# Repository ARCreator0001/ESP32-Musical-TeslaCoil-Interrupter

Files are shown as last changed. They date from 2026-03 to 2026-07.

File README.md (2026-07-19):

# ESP32 Musical Tesla Coil interrupter - a truly versatile interrupter








Demo video of it working!!(YouTube)
[Demo!!](https://youtu.be/YgG9X8sHGf4)

Link to onshape: [Onshape](https://cad.onshape.com/documents/e0858d62bc807065493100b9/w/9e573f9273f6c5cefa0e0909/e/5fb6c5c268f4d3541bf88c26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)

## Why? 

I always wanted a good, cheap and reliable Tesla Coil Interrupter but as of now, there is not a good, easily accessible proper product like project or prototype I could get. And I needed a good, feature rich, safe interrupter too for my Tesla Coil journey since all my prototype perfboard designs failed of the harsh environments. I wanted something close to the OneTesla SD interrupter but a modern touch, more modern features that make sense and a lot of new features that is essential nowadays. 
 
That is why I set out to build a good, ESP32S3 based Tesla Coil interrupter that is reliable as a product and robust for the environments of a Tesla Coil.

## About the project in a nutshell

It is a portable fiber optic(POF) output interrupter designed to interrupt DRSSTCs and SSTCs safely with limits, and even audio modulate the interruption for musical tesla coil arcs! 
It has an easy to use UI, simple settings on the frontend, and importantly, it has so much limits and safeties specifically tuned for DRSSTC to ensure the coil and driver is not stressed very much. 

It is powered by a 9V battery inside the battery compartment by default, but USB C power input(compatible with modern chargers) can also be used by changing a mode select jumper. 

## Hardware it uses and more features

- Compact 16x2 LCD for displaying information. 
- Micro SDcard slot for music. It supports playing  .mid file and even OneTesla's propietary binary music data file (.omd) used kn their interrupters as a fallback. 
- 4 Voices support for midi files(2 voice for  .omd) means more complex music can be played! 
- Optical fiber output (POF 1mm) for output to coil driver, ensuring isolation from EM radiation and noise. 
- Live mode MIDI over serial through DIN 5 jack and also USB MIDI support is present (usb midi needs firmware addition yet) 
- Tactile Buttons and Rotary encoder(setting volume and also for selection) for the UI and adjustments in operation. There is also a latching power switch. 
- Fixed-frequency mode with adjustable freq and volume

## How to use. 

- Press the latching switch. The device will turn on and display by default Fixed Mode. 
- Left&Right buttons can be used to scroll through menus. Select is done by pressing on the rotary encodee knob till thr encoder knob clicks. 
- The middle button(used to be select)will become the new exit button to exit out of modes(yet to be totally verified in firmware)
- To play fixed freq pulses select fixed mode. Rotating rotary knob when the Freq is selected will change the frequency, to select volume, left or right button is used till bottom row of LCD is highlighted,then volume(duty cycle) can be adjusted by rotary knob. Middle button will be used to exit the mode.Note optical output starts once in fixed mode(default 20Hz with minimum volume) and will stop once exited. 

- For live modes(Live&MIDI BLE), an input such as from a keyboard or any device can be given to the interrupter in live. The device will act as Midi receiver. 

# Firmware details

## Build & Upload (Arduino IDE)
 Please install the ESP32 board core before proceeding
 The interrupter after building needs to be programmed with firmware. The latest firmware files can be accessed in releases. 

1. Board: Select **ESP32S3 Devkit** (or ESP32S3 Dev Module)

2. Libraries: Unlike previous firmware versions, Now the libraries are included within the firmware locally

3. Select correct COM port, Upload.

## Controls

- **Main menu**: LEFT/RIGHT to navigate; SELECT(rotary's switch) to enter, soon mid button for exiting. 
- **Fixed mode**: short SELECT toggles freq/volume adjust; Press middle button to exit

- **Live mode&MIDI BLE**: SELECT activates and exits live mode. Status is shown in LCD. 

- **SD browser**:LEFT/RIGHT to navigate through files & directories; SELECT opens folder or plays file; press middle button to go one up if inside directories or exit the mode if in root directory. 

- **Playback**: SELECT starts & stops; Rotary knob rotation adjusts volume bar(the coil duty)

## File format

- It accepts .mid MIDI files. More than 4 channels won't play correctly, always keep melody in first two as they are preferred internally. 
-It also uses .omd file but it is a limited fallback only, it is a cut down midi file format OneTesla used so your music may not play properly. Soon  .omd will be disabled by default. 

# CAD images and images of PCB & schematic





PCB images








All mech parts in parts studio



Exploded views





Here is schematic
SCH_ESP32 SD Interrupter_1-Sheet_1_2026-03-31

# Bill of materials

| Part name | Qty required(not ordered due to MOQs) | Source | Price | Actual Price with taxes & shipping | Links |
| --- | --- | --- | --- | --- | --- |
| PCB board fabrication | 1 used 5 MOQ |Lion Circuits or ~~Robu.in~~ | ~~robu(₹3556/$37.7)~~, Lion ₹2983 $31.74 | ~~robu(same)~~,Lion ₹2983 $31.74 |Cannot link to quote|
| 2.54MM male Pin headers | 5 pins(2+3) | Local shop | Already own | Already own | |
|Power Switch Latching|1|LCSC|$0.84|$0.84|[link](https://www.lcsc.com/product-detail/C22386787.html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)|
|USB C Port Connector|1|LCSC|$1.06|$1.06|[link](https://www.lcsc.com/product-detail/C20624793.html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)|
|Tactile Button|3|LCSC|$0.06|$0.06|[link](https://www.lcsc.com/product-detail/C7528723.html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)|
|OptoTransmitter HFBR-1521Z|1|LCSC|$7.65|$7.65|[link](https://www.lcsc.com/product-detail/C188712.html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)|
|AMS1117-3.3 regulator|1|LCSC|$1.13|$1.13|[link](https://www.lcsc.com/product-detail/C6186.html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)|
|AMS1117-5.0 regulator|1|LCSC|$1.19|$1.19|[link](https://www.lcsc.com/product-detail/C6187.html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)|
|ESP32S3 Wroom 1 N8|1|LCSC|$5.42|$5.42|[link](https://www.lcsc.com/product-detail/C2913198.html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)|
|10uF 25V Aluminum Electrolytic Cap|1|LCSC|$0.49|$0.49|[link](https://www.lcsc.com/product-detail/C43846.html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)|
|100nF 25V 0805 Ceramic cap|8|LCSC|$0.18|$0.18|[link](https://www.lcsc.com/product-detail/C53084462.html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)|
|470Ω 150V Thin Film Resistor|1|LCSC|$0.70|$0.70|[link](https://www.lcsc.com/product-detail/C479100.html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)|
|220Ω 0805 Res|1|LCSC|$1.70|$1.70|[link](https://www.lcsc.com/product-detail/C186237.html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)|
|180Ω 0805 Res|1|LCSC|$0.49|$0.49|[link](https://www.lcsc.com/product-detail/C313842.html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)|
|33ohm 0805 Res|1|LCSC|$0.41|$0.41|[link](https://www.lcsc.com/product-detail/C557530.html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)|
|Rotary encoder EC11E18244A5|1|LCSC|$2.05|$2.05|[link](https://www.lcsc.com/product-detail/C255515.html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)|
|Micro SD TF card port|1|LCSC|$0.73|$0.73|[link](https://www.lcsc.com/product-detail/C111196.html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)|
|10K Resistor array 1206|1|robu.in|₹ 2.28 $0.0243|₹ 2.28 $0.0243|[link](https://robu.in/product/cay16-1002f4lf-bourns-4-%c2%b11-10k%cf%89-62-5mw-%c2%b1200ppm-%e2%84%83-1206-resistor-networks-arrays-rohs/)|
|0805 LED Green|1|robu.in|₹ 2.62 $0.0279|₹ 2.62 $0.0279|[link](https://robu.in/product/0805-surface-mount-led-green-50-pcs/)|
|0805 LED Red|2|robu.in|₹2.36 $0.0252|₹2.36 $0.0252|[link](https://robu.in/product/0805-surface-mount-led-red-50-pcs/)|
|DSS34 diode|2|robu.in|₹ 9.58 $0.1021|₹ 9.58 $0.1021|[link](https://robu.in/product/dss34-slkor-sod-123fl-schottky-diodes-rohs/)|
|1N4148W 1206 Diode|2|robu.in|₹ 1.70 $0.0181| ₹ 1.70 $0.181|[link](https://robu.in/product/1n4148w-sod-123-1206-diodereel-of-3000/)|
|SS8050S-FOSAN-SOT-23 Bipolar (BJT)|1|robu.in|₹1.82 $0.0194| ₹1.82 $0.0194|[link](https://robu.in/product/ss8050s-fosan-sot-23-bipolar-bjt-rohs/)|
|510kΩ 0805 res|1|robu.in|₹0.21 $0.0022||[link](https://robu.in/product/0805w8j0514t5e-uniohm-royal-ohm-125mw-thick-film-resistors-150v-%c2%b1100ppm-%e2%84%83-%c2%b15-510k%cf%89-0805-chip-resistor-surface-mount-ro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)|
|5.1kΩ 0805 res|2|robu.in|₹ 1.96 $0.0209|₹ 1.96 $0.0209|[link](https://robu.in/product/ac0805fr-075k1l-yageo-res-thick-film-0805-5-1k-ohm-1-0-125w1-8w-%c2%b1100ppm-c-pad-smd-t-r-automotive-aec-q200/)|
|2.2Kohm 0805 res|1|robu.in|₹ 0.42 $0.0045|₹ 0.42 $0.0045|[link](https://robu.in/product/ac0805jr-072k2l-yageo-res-thick-film-0805-2-2k-ohm-5-0-125w1-8w-%c2%b1100ppm-c-pad-smd-t-r-automotive-aec-q200/)|
|47Ω 0805 res|1|robu.in|₹ 0.20 $0.0021|₹ 0.20 $0.0021|[link](https://robu.in/product/0805w8f470jt5e-uniohm-royal-ohm-125mw-thick-film-resistors-150v-%c2%b11-%c2%b1200ppm-%e2%84%83-47%cf%89-0805-chip-resistor-surface-mount-rohs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)|
|TS-1088-AR02016 Switch|2|robu.in|₹8.43 $0.0899|₹8.43 $0.0899|[link](https://robu.in/product/1-month-warranty-470/)|
|TLJR106M010S2000-KYOCERA AVX-10uF 10V cap|1|robu.in|₹26 $0.2772|₹26 $0.2772|[link](https://robu.in/product/tljr106m010s2000-kyocera-avx-10uf-10v-2%cf%89-%c2%b120-0805-tantalum-capacitors-rohs/)|
|16V 10uF X5R 0805|2|robu.in|₹1.96 $0.0209|₹1.96 $0.0209|[link](https://robu.in/product/cl21a106kofnnne-samsang-16v-10uf-x5r-%c2%b110-0805-multilayer-ceramic-capacitors-mlcc-smd-smt-rohs/)|
|1.3Kohm 0805 res|1|robu.in|₹ 1.96 $0.021|₹ 1.96 $0.021|[link](https://robu.in/product/rt0805fre071k3l-yageo-125mw-thin-film-resistor-%c2%b150ppm-%e2%84%83-%c2%b11-1-3k%cf%89-0805-chip-resistor-surface-mount-rohs/)|
|M2 X 12mm Female to Female Brass with Nickel plating Hex Threaded Standoff Spacer|4|onlyscrews.in|₹24.8 $0.2644|₹24.8 $0.2644|[link](https://onlyscrews.in/products/m2-x-12mm-female-to-female-brass-with-nickel-plating-hex-threaded-standoff-spacer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)|
|M2 X 10mm Hex (Allen) Socket Head High Tensile(12.9) Black oxide screw (Dia. 2mm, Length 10mm)|8|onlyscrews.in|₹28.8 $0.307|₹28.8 $0.307|[link](https://onlyscrews.in/products/m2-x-10mm-hex-allen-socket-head-high-tensile12-9-black-oxide-screw-dia-2mm-length-10mm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)|
|M2 Plain Washer SS304 (ID. 2.1mm OD:4.5mm T:0.5mm)|4|onlyscrews.in|₹2.4 $0.0256|₹2.4 $0.0256|[link](https://onlyscrews.in/products/m2-x-6mm-hex-allen-socket-head-high-tensile12-9-black-oxide-screw-dia-2mm-length-6mm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)|
|M2 Hex Nut Mild Steel with White Zinc Plating (Dia. 2mm)|4|onlyscrews.in|₹4 $0.0426|₹0.0426|[link](https://onlyscrews.in/products/m2-hex-nut-mild-steel-dia-2mm?variant=50252401246521)|
|M2 X 4mm Brass Threaded Inserts (Dia. 2mm, Length 4mm)|8|onlyscrews.in|₹21.6 $0.23|₹21.6 $0.23|[link](https://onlyscrews.in/products/m2-x-4mm-brass-threaded-inserts?variant=49423172829497)|
|16*2 I2C LCD|1|Local shop|Alr own|Alr own| |
|9V PP3 Battery|1|Local shop|Alr own|Alr own| |
|9V PP3 Battery connector clip|1|Local shop|Will purchase myself|Will purchase myself| |
|Sum||||$58.8217 excluding shipping cost of LCSC of $29.25 and $0.5224 of Robu,LionCircuits is free shipping,OnlyScrews has shipping cost of $0.6397| |
|Grand Total|||||$89.2338| |

Link to onshape doc: [Onshape](https://cad.onshape.com/documents/e0858d62bc807065493100b9/w/9e573f9273f6c5cefa0e0909/e/5fb6c5c268f4d3541bf88c26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)

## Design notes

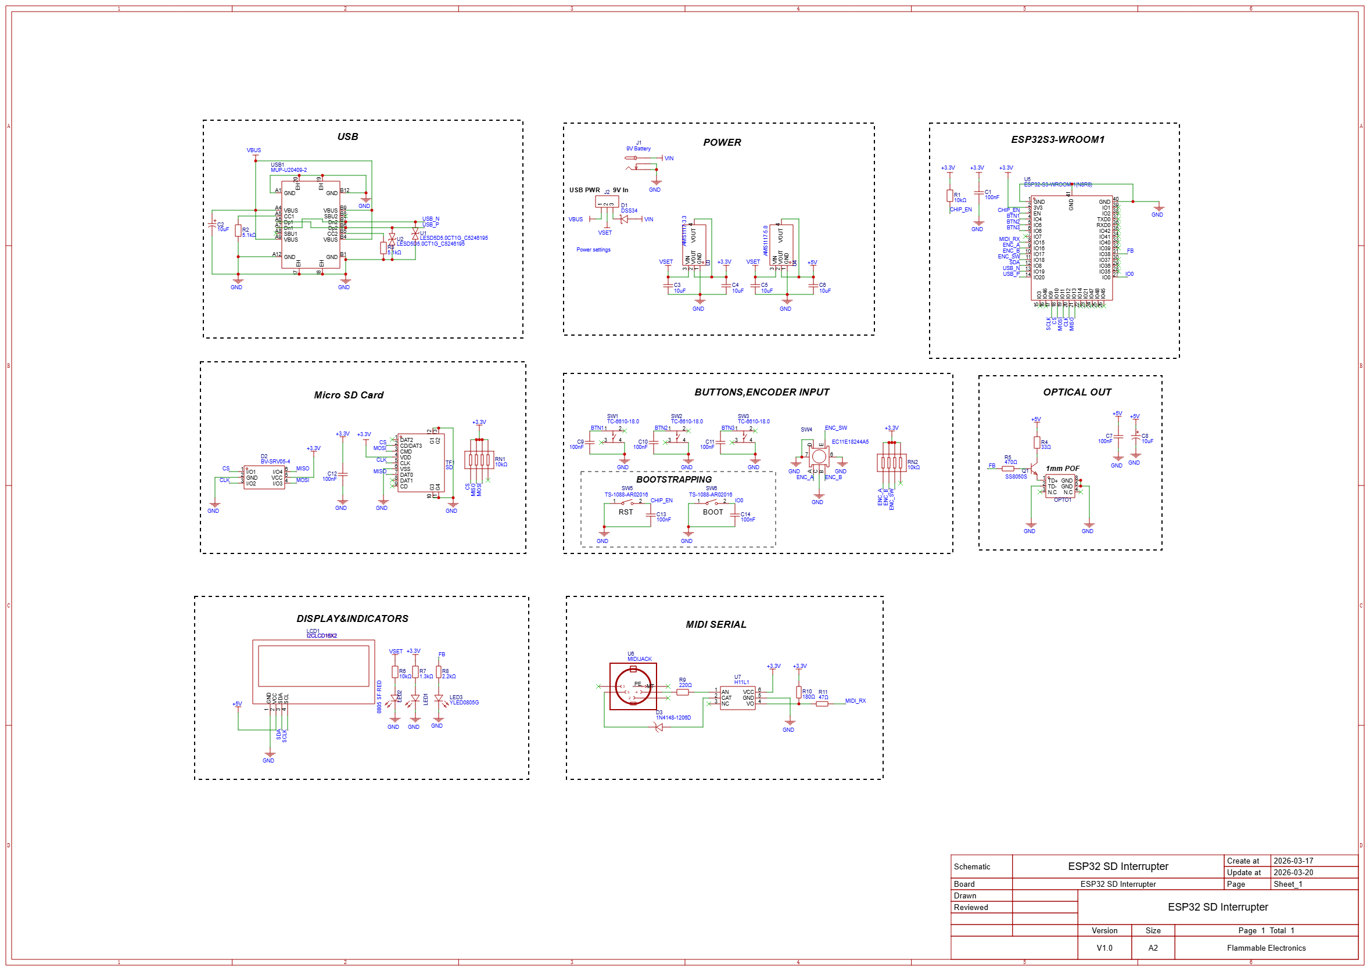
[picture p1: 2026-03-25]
SCH_ESP32 SD Interrupter_1-Sheet_1_2026-03-23.png

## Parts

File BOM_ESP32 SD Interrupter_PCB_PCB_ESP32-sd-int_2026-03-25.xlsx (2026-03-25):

No. | Quantity | Comment | Designator | Footprint | Value | Manufacturer Part | Manufacturer | Supplier Part | Supplier | Name
1 | 6 | 100nF | C1,C9,C10,C11,C13,C14 | C0805 |  | C2012X7R1H104KT0J0N | TDK | C76644 | LCSC | 100nF
2 | 1 | 10uF | C2 | CAP-SMD_L3.2-W2.8-FD |  | T494B106K010AT | KEMET(基美) | C2798063 | LCSC | 10uF
3 | 4 | 10uF | C3,C4,C5,C6 | C0805 |  | CL21A106KOQNNNE | SAMSUNG(三星) | C1713 | LCSC | 10uF
4 | 2 | 100nF | C7,C12 | C0805 |  | CC0805X7R25V104KN | TORCH(火炬) | C53084462 | LCSC | 100nF
5 | 1 | 10uF | C8 | CAP-TH_BD4.0-P1.50-D0.8-FD |  | KF106M025C05RR0VH2FP0 | Chengx(承兴) | C43846 | LCSC | 10uF
6 | 1 | DSS34 | D1 | SOD-123_L2.8-W1.8-LS3.7-RD |  | DSS34 | 星海 | C84632 | LCSC | DSS34
7 | 1 | BV-SRV05-4 | D2 | SOT-23-6_L2.9-W1.6-P0.95-LS2.8-BL |  | BV-SRV05-4 | Bencent(槟城) | C409437 | LCSC | BV-SRV05-4
8 | 1 | 1N4148-1206D | D3 | LL-34_L3.5-W1.5-R-RD |  | 1N4148-1206D | null | C9900004118 | LCSC | 1N4148-1206D
9 | 1 | 9V Battery | J1 | DC-IN-TH_DC-5520-1 |  | DC-005 2.0 | BOOMELE(博穆精密) | C16214 | LCSC | 9V Battery
10 | 1 | Power settings | J2 | HDR-TH_3P-P2.54-V-M-1 |  | 2.54-1*3P针 | BOOMELE(博穆精密) | C49257 | LCSC | Power settings
11 | 1 | I2CLCD16X2 | LCD1 | I2CLCD16X2 |  |  |  |  |  | I2CLCD16X2
12 | 1 | 0805 SF-RED | LED1 | LED0805-RD_RED |  | 0805 SF-Red | null | C9900020303 | LCSC | 0805 SF-RED
13 | 1 | SF-RED | LED2 | LED0805-RD_RED |  | 0805 SF-Red | null | C9900020303 | LCSC | SF-RED
14 | 1 | YLED0805G | LED3 | LED0805-FD-GREEN |  | YLED0805G | YONGYUTAI(永裕泰) | C25170728 | LCSC | YLED0805G
15 | 1 | HFBR-1521Z | OPTO1 | CONN-TH_HFBR-1521Z |  | HFBR-1521Z | Broadcom(博通) | C188712 | LCSC | HFBR-1521Z
16 | 1 | SS8050S | Q1 | SOT-23-3_L2.9-W1.3-P0.95-LS2.4-BR |  | SS8050S | FOSAN(富捷/富信) | C22395784 | LCSC | SS8050S
17 | 2 | 10kΩ | R1,R6 | R0805 |  | TNPW080510K0BETA | VISHAY(威世) | C2076274 | LCSC | 10kΩ
18 | 2 | 5.1kΩ | R2,R3 | R0805 |  | HoAR0805-1/8W-5.1KR-0.1%-TCR25 | Milliohm(毫欧) | C2912598 | LCSC | 5.1kΩ
19 | 1 | 33Ω | R4 | R0805 |  | SR0805FR-4733RL | YAGEO(国巨) | C6234260 | LCSC | 33Ω
20 | 1 | 470Ω | R5 | R0805 |  | AECR0805F470RK9 | RESI(开步睿思) | C328396 | LCSC | 470Ω
21 | 1 | 1.3kΩ | R7 | R0805 |  | FRQ0805F1301TS | FOJAN(富捷) | C7468626 | LCSC | 1.3kΩ
22 | 1 | 2.2kΩ | R8 | R0805 |  | RMC08052.2K1%N | Tyohm(幸亚电阻) | C325769 | LCSC | 2.2kΩ
23 | 1 | 220Ω | R9 | R0805 |  | 0805W8D2200T5E | UNI-ROYAL(厚声) | C407469 | LCSC | 220Ω
24 | 1 | 180Ω | R10 | R0805 |  | 0805W8F1800T5E | UNI-ROYAL(厚声) | C25270 | LCSC | 180Ω
25 | 1 | 47Ω | R11 | R0805 |  | 0805W8F470JT5E | UNI-ROYAL(厚声) | C17714 | LCSC | 47Ω
26 | 2 | 10kΩ | RN1,RN2 | RES-ARRAY-SMD_1206-8P-L5.1-W3.1-BL |  | CRA064RJ10K0E04Z | EVER OHMS(天二科技) | C183863 | LCSC | 10kΩ
27 | 3 | TC-6610-18.0 | SW1,SW2,SW3 | SW-TH_4P-L6.0-W6.0-P4.50-LS6.5 |  | TC-6610-18.0 | FG(富港) | C7528723 | LCSC | TC-6610-18.0
28 | 1 | EC11E18244A5 | SW4 | SW-TH_EC11E18244A5 |  | EC11E18244A5 | ALPSALPINE(阿尔卑斯阿尔派) | C255515 | LCSC | EC11E18244A5
29 | 1 | TS-1088-AR02016 | SW5 | SW-SMD_L3.9-W3.0-P4.45 |  | C2012X7R1H104KT0J0N | TDK | C76644 | LCSC | TS-1088-AR02016
30 | 1 | TS-1088-AR02016 | SW6 | SW-SMD_L3.9-W3.0-P4.45 |  | TS-1088-AR02016 | XUNPU(讯普) | C720477 | LCSC | TS-1088-AR02016
31 | 1 | SD | TF1 | TF-SMD_TF-15-15 |  | SD | null | C9900023771 | LCSC | SD
32 | 2 | LESD5D5.0CT1G_C5246195 | U1,U2 | SOD-523_L1.2-W0.8-LS1.6-BI |  | LESD5D5.0CT1G | Leiditech(雷卯电子) | C5246195 | LCSC | LESD5D5.0CT1G_C5246195
33 | 1 | AMS1117-3.3 | U3 | SOT-223-3_L6.5-W3.4-P2.30-LS7.0-BR |  | AMS1117-3.3 | AMS | C6186 | LCSC | AMS1117-3.3
34 | 1 | AMS1117-5.0 | U4 | SOT-223_L6.5-W3.5-P2.30-LS7.0-BR |  | AMS1117-5.0 | AMS | C6187 | LCSC | AMS1117-5.0
35 | 1 | ESP32-S3-WROOM-1(N8R8) | U5 | WIRELM-SMD_ESP32-S3-WROOM-1 |  | ESP32-S3-WROOM-1-N8R8 | ESPRESSIF(乐鑫) | C2913201 | LCSC | ESP32-S3-WROOM-1(N8R8)
36 | 1 | MIDIJACK | U6 | CP-2350 |  |  |  |  |  | MIDIJACK
37 | 1 | H11L1 | U7 | DIP-6_L8.5-W6.4-P2.54-LS7.6-BL |  | H11L1 | EVERLIGHT(亿光) | C78588 | LCSC | H11L1
38 | 1 | MUP-U20409-2 | USB1 | USB-C-SMD_MUP-U20409-2 |  | MUP-U20409-2 | MUP(德海威) | C5373202 | LCSC | MUP-U20409-2

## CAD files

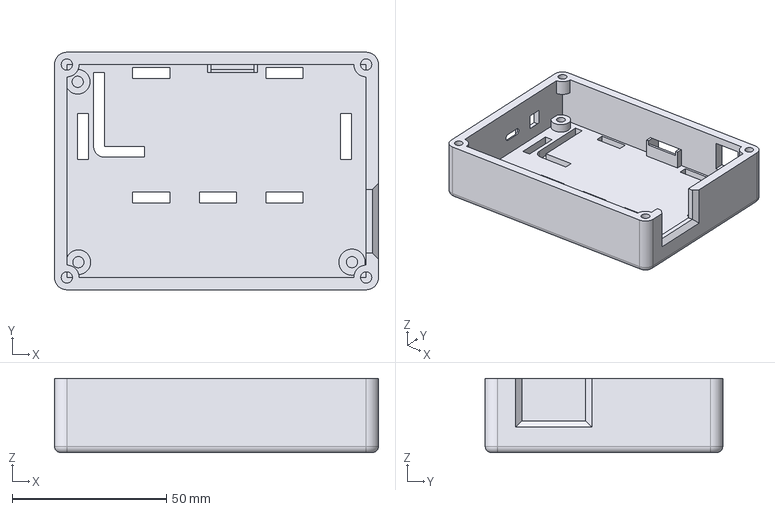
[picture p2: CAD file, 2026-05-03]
CAD files/Case parts 3D files/3D-ESP32MusicInt-Casemain.step
105.0 x 77.0 x 24.0 mm

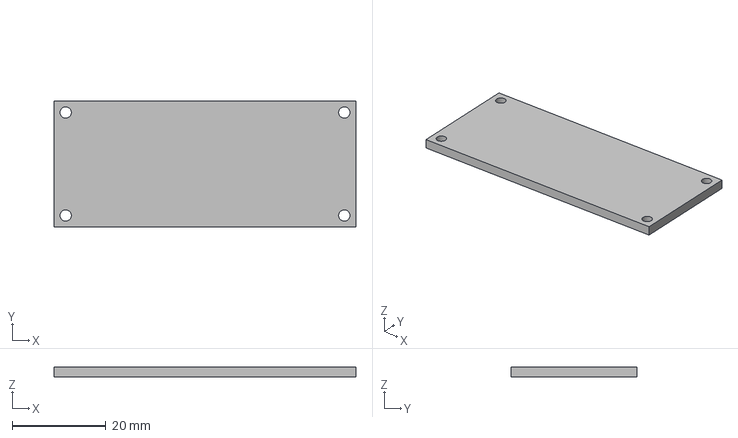
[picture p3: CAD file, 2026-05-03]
CAD files/Case parts 3D files/3D-ESP32MusicInt-CaseBatteryLid.step
64.5 x 27.0 x 2.20 mm

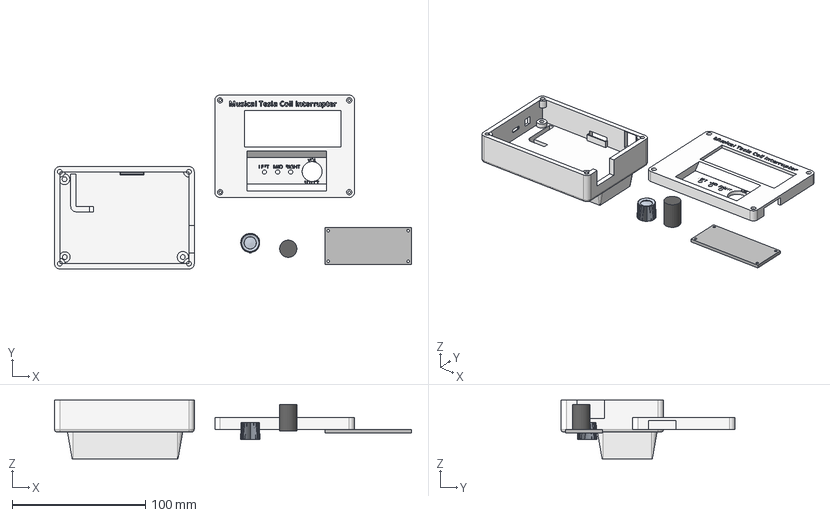
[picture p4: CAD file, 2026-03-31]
CAD files/ESP32MusicalInterrupterCasePartDoc.step
268.2 x 130.7 x 44.0 mm

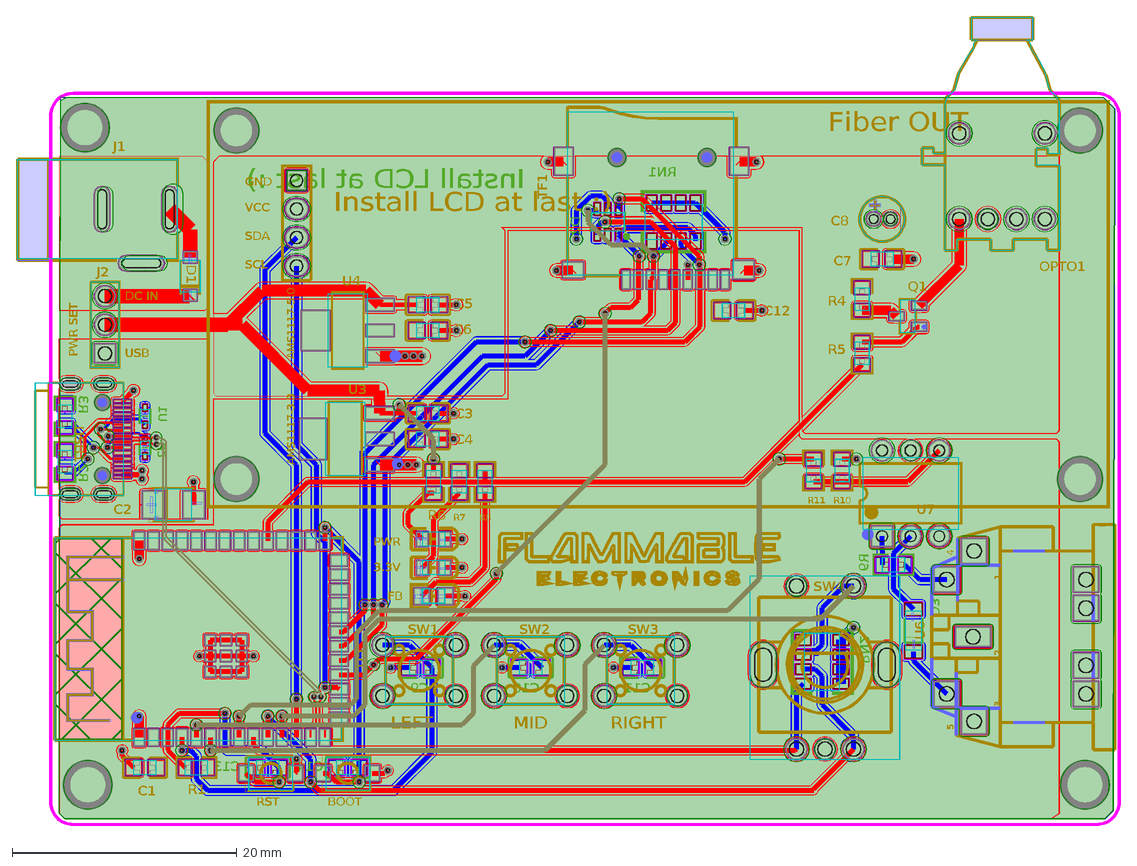
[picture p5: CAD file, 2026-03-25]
DXF_PCB_PCB_ESP32-sd-int_2026-03-25_AutoCAD2007.dxf
Install LCD at last :)
RN1
D3
RN2
U1
U2
D2
C9
C10
C11
C13
C14
R2
R3
R9
BOOT
RST
LEFT
MID
RIGHT
Fiber OUT
PWR SET
USB
DC IN
GND
VCC
SDA
SCL
PWR
3.3V
FB
AMS1117-3.3
AMS1117-5.0
C1
C2
C8
D1
J1
R4
R5
R7
R10
R11
SW4
U3
U4
U5
2
4
5
3
1
U6
U7
USB1
R8
J2
Q1
TF1
C3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

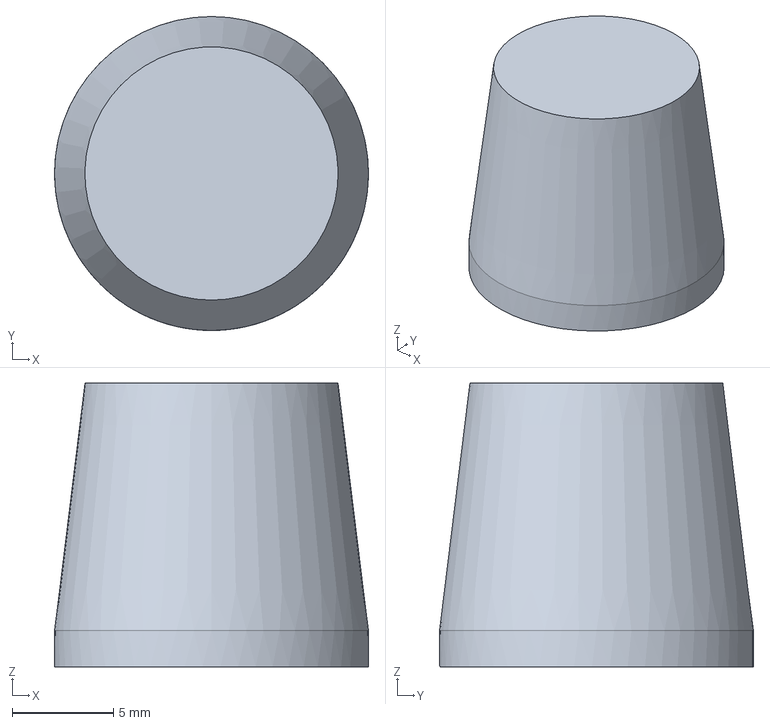
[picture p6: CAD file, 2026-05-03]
CAD files/Case parts 3D files/3D-ESP32MusicInt-Knob.step
15.5 x 15.5 x 14.0 mm

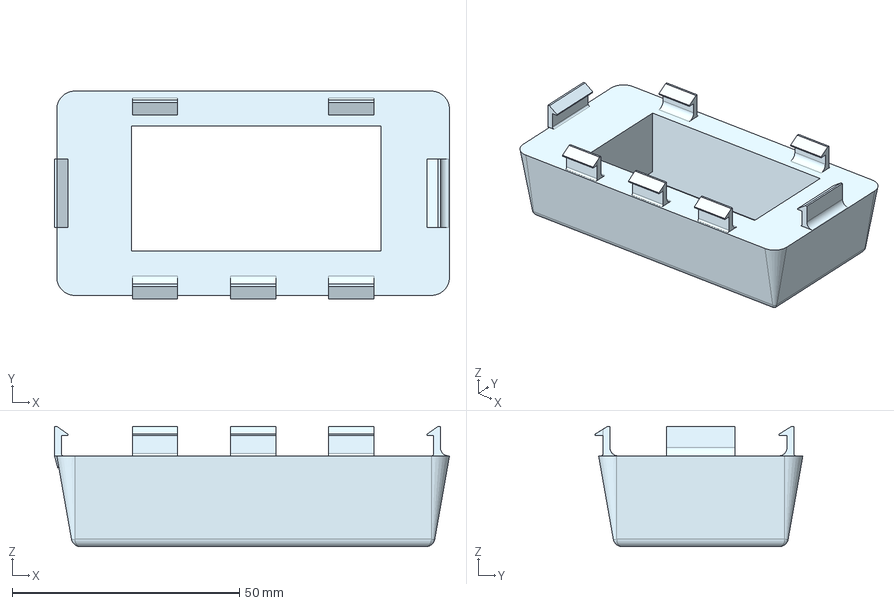
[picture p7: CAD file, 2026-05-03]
CAD files/Case parts 3D files/3D-ESP32MusicInt-CaseBattHolder.step
87.0 x 45.8 x 26.5 mm

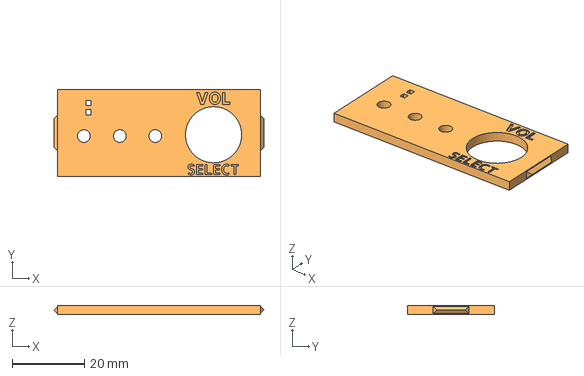
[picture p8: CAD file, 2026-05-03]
CAD files/Case parts 3D files/3D-ESP32MusicInt-CaseUIPanel.step
58.0 x 24.0 x 2.50 mm

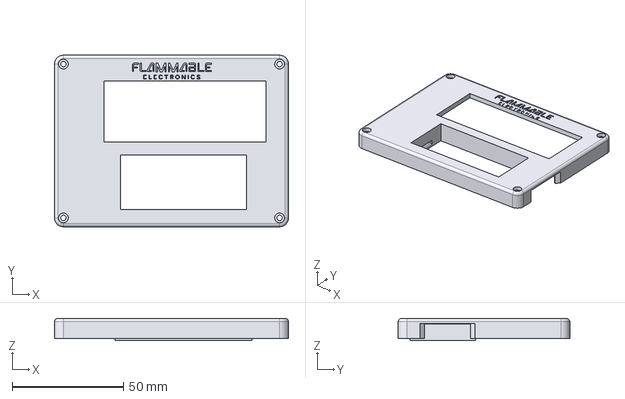
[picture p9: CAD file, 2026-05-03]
CAD files/Case parts 3D files/3D-ESP32MusicInt-CaseLid.step
105.0 x 77.0 x 10.0 mm

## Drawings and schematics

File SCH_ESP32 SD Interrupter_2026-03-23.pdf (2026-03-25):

USB | POWER | ESP32S3-WROOM1

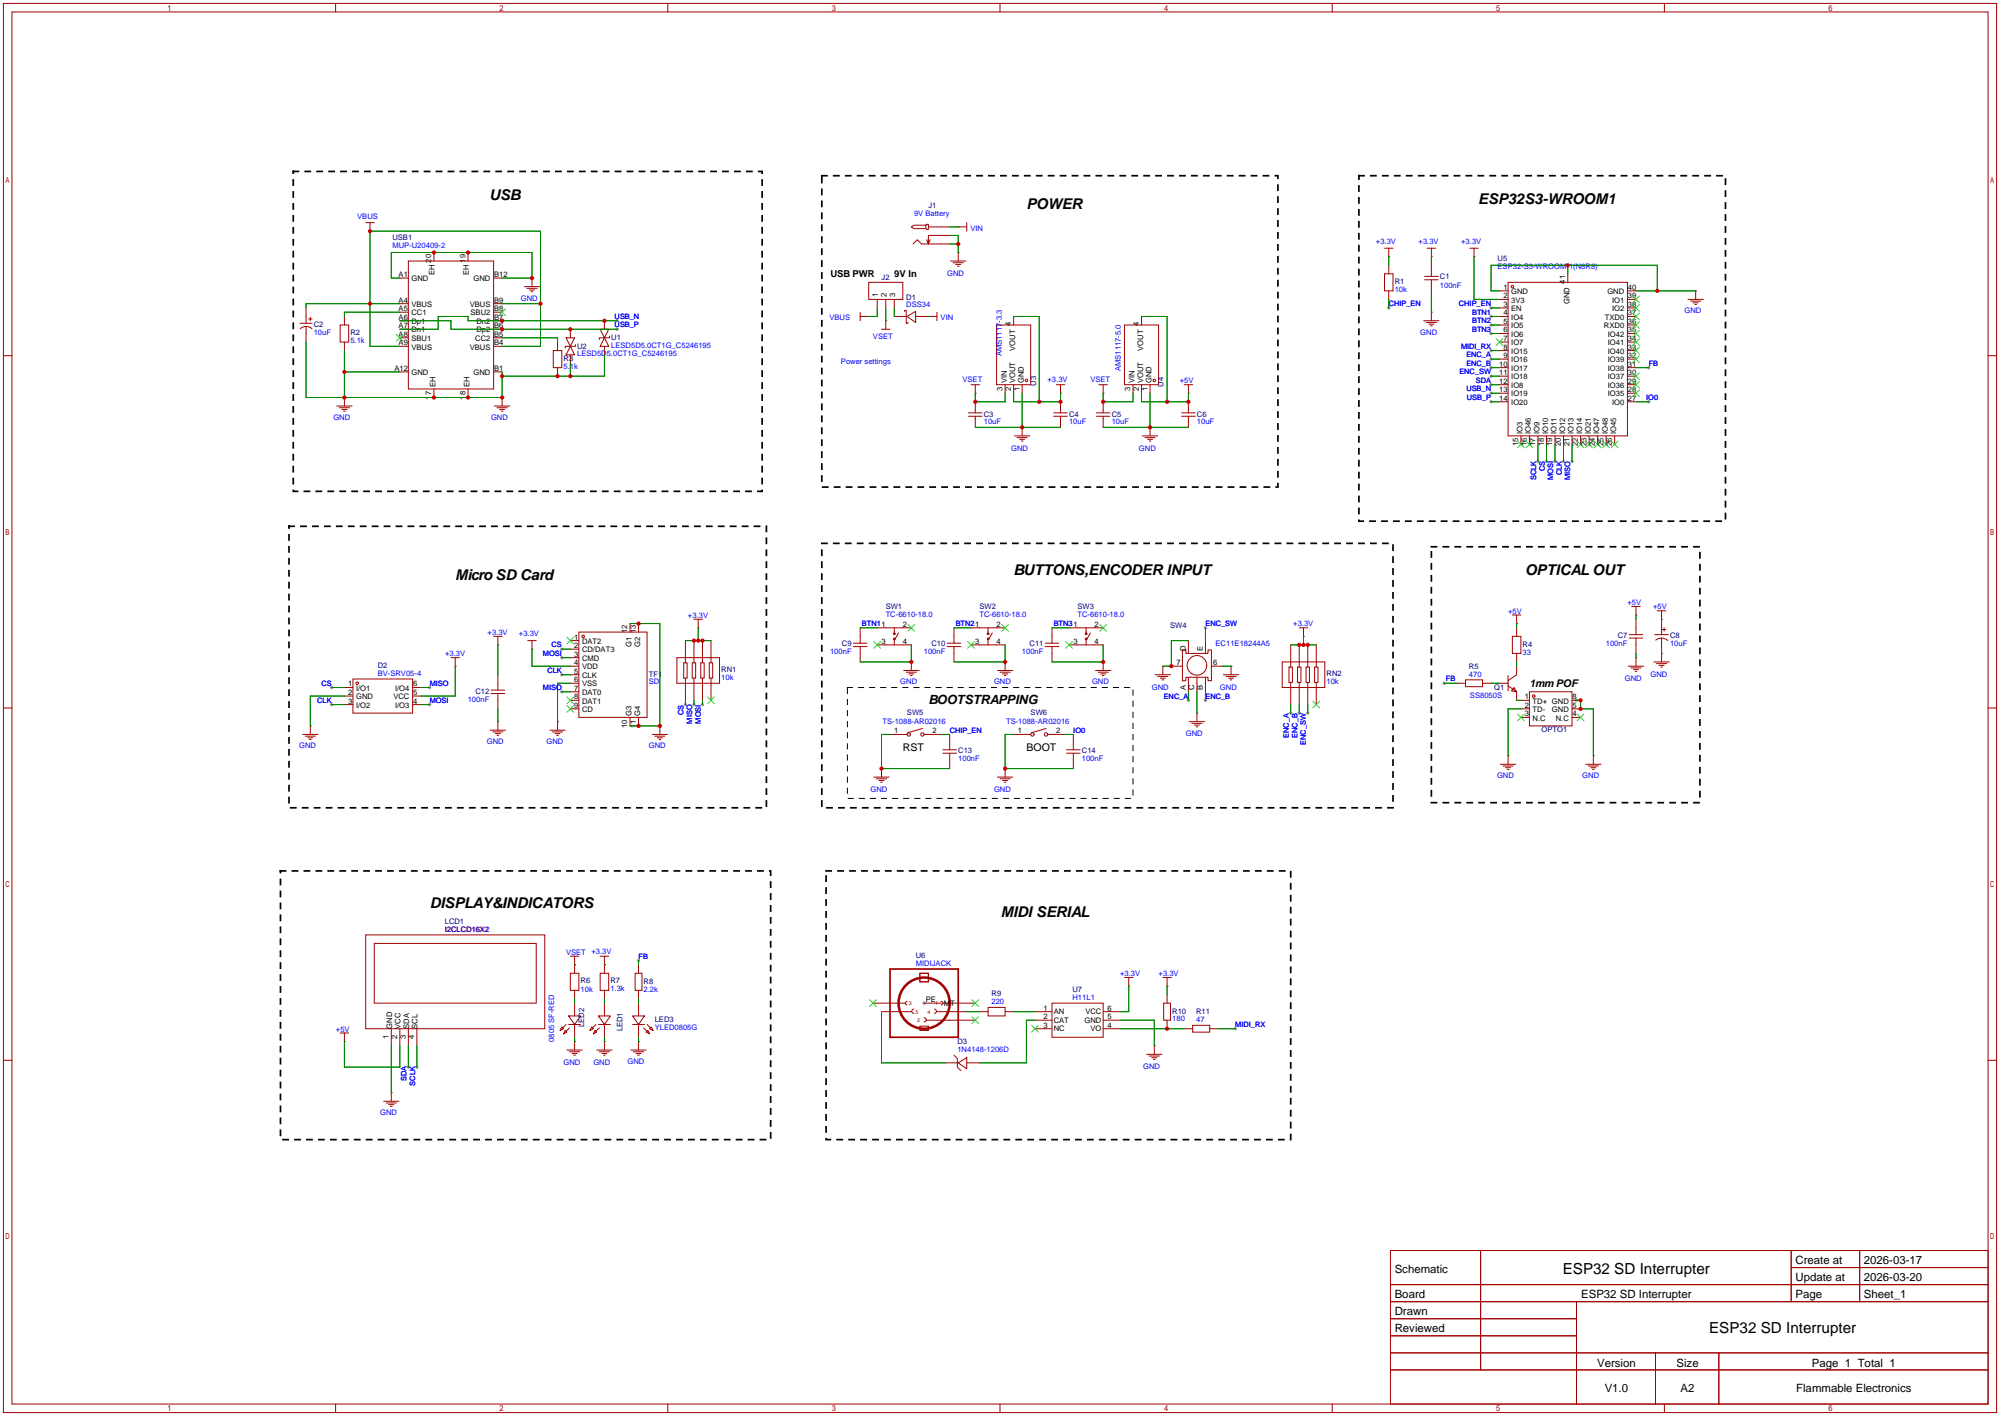
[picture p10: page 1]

Schematic | ESP32 SD Interrupter | Create at | 2026-03-17

Update at | 2026-03-20

Board | ESP32 SD Interrupter | Page | Sheet_1
Drawn | | ESP32 SD Interrupter
Reviewed

Version | Size | Page 1 Total 1
V1.0 | A2 | Flammable Electronics

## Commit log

2026-03-25 Schematic for ESP32S3 based DIY board
2026-03-25 BOM for PCB and PCB files and 3D files
    [BOM_ESP32 SD Interrupter_PCB_PCB_ESP32-sd-int_2026-03-25.xlsx, DXF_PCB_PCB_ESP32-sd-int_2026-03-25_AutoCAD2007.dxf]
2026-03-25 Changed board layout and few critical improvements in routing
    [BOM_ESP32 SD Interrupter_PCB_PCB_ESP32-sd-int_2026-03-25.xlsx, DXF_PCB_PCB_ESP32-sd-int_2026-03-25_AutoCAD2007.dxf]
2026-05-03 Case Redesign
    Improved for printability focused on DFAM,made multiple snap in parts
    [3D-ESP32MusicInt-Battery-lid.step, 3D-ESP32MusicInt-CaseBattHolder.step, 3D-ESP32MusicInt-CaseBatteryLid.step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]
